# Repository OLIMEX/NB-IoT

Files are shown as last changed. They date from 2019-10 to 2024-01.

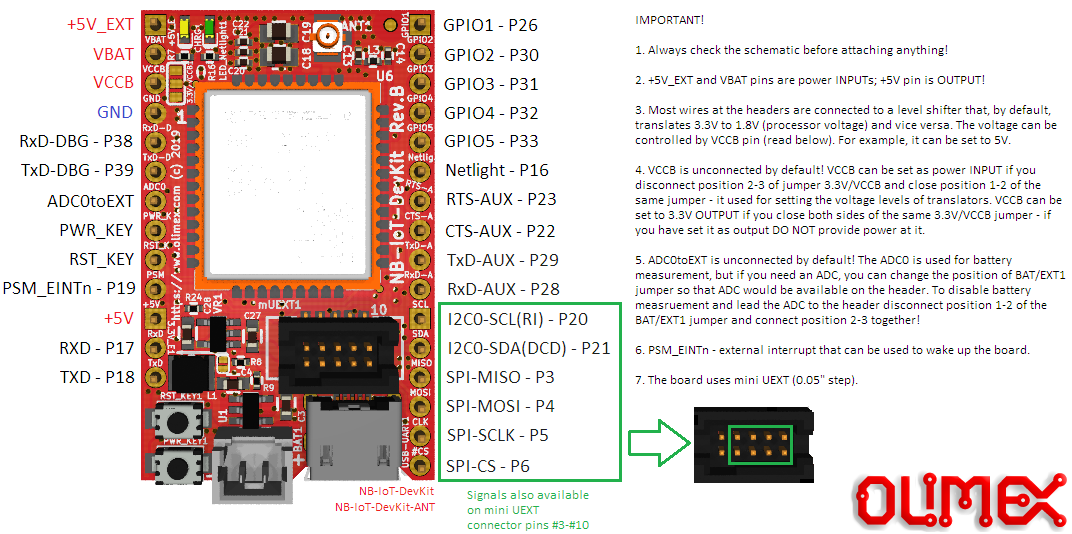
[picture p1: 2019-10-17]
HARDWARE/NB-IoT-DevKit-pinout.png

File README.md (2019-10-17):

# NB-IoT
NB-IoT is LPWAN technology for IoT with many advantages over LoRa and SigFox.

NB-IoT technology works over existing GSM network. This means all existing GSM networks with LTE can support NB-IoT if the protocol is installed by your GSM operator.
One base cell can talk up to 100 000 NB-IoT nodes. One base cell can establish connection in urban area 1-10km and in rural area 10-100km
One NB-IoT node can last on battery up to 10 years if less 200 bytes per day are transmitted

# NB-IoT-DevKit board has these features:
- BC-66 all world wide GSM bands coverage
- NB-IoT 25.5 kbps up and down link
- Ultra low power design
- Build in Li-Po battery charger
- Nano SIM
- Level shifters for 5x GPIOs, I2C, SPI, UART
- Micro UEXT connector
- U.FL antenna connector
- Status LEDs
- Dimensions 40x25 mm

# License
- Hardware is with CERN OHL v1.2 license
- Software is with GPL3 license
- Documentation is with CC BY-SA 4.0 license

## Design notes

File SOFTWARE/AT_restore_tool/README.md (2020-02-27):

This is AT restore firmware procedure for Olimex NB-IoT-Devkit

It should be used if you overwrote the AT command firmware. It is made for Linux.

####################################################

Preparation:

Download all files from the folder where this README is located. 

In order to install a patched CH340 driver, please run "install_ch340.sh" file:

1. Open terminal in the directory containing "install_ch340.sh".
2. Execute the following: ./install_ch340.sh

The reason is that this script allows CH340T to operate at higher baudrate and enables auto-reset 
function, which is not supported with the official ch340 drivers for Linux.

If you have trouble with the shell script, you can also find the driver here:
https://github.com/OLIMEX/ch340-dkms

If you update the kernel of your Linux installation, you might need to run the installation again!

####################################################

Once the driver is successfully installed:

1. Connect Olimex NB-IoT-Devkit board to your PC

2. Open new terminal in the current directory

3. Enter down: ./REPAIR.SH SN IMEI

where SN and IMEI numbers are written on the top of Quectel BC66 chip. 

Notice that the repair script has auto-detect, so make sure you have only one peripheral using
CH340 connected to the computer.

####################################################

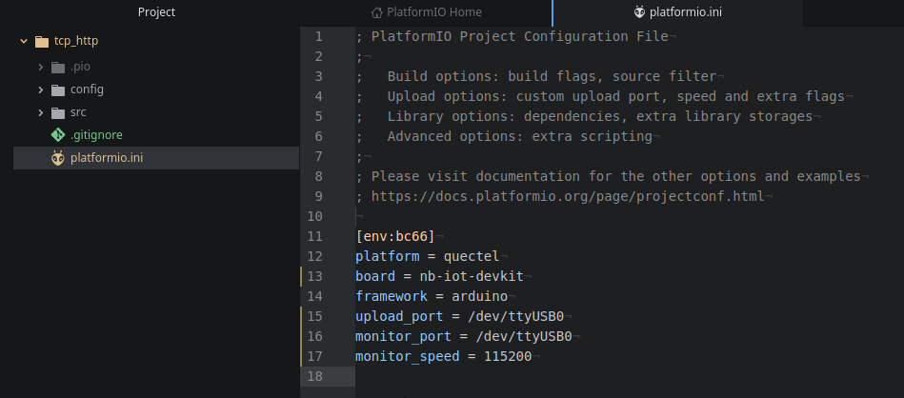
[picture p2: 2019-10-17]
SOFTWARE/images/5_platform_ini.png

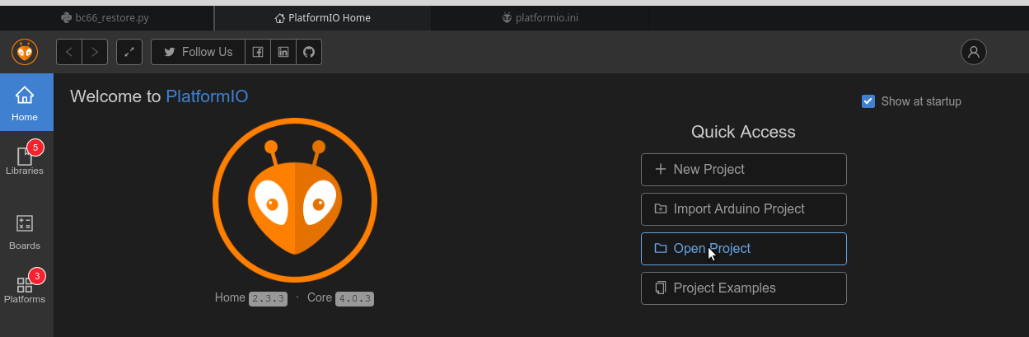
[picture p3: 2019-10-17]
SOFTWARE/images/3_open_project.png

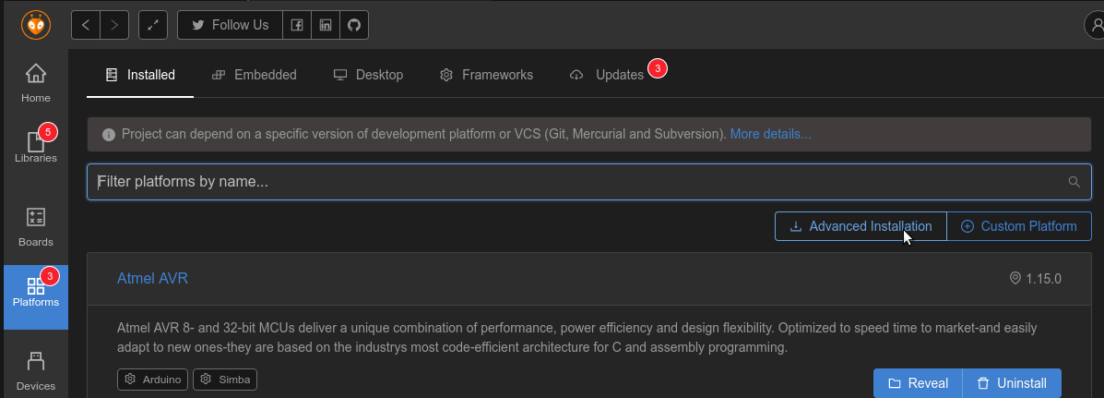
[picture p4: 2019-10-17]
SOFTWARE/images/1_advanced.png

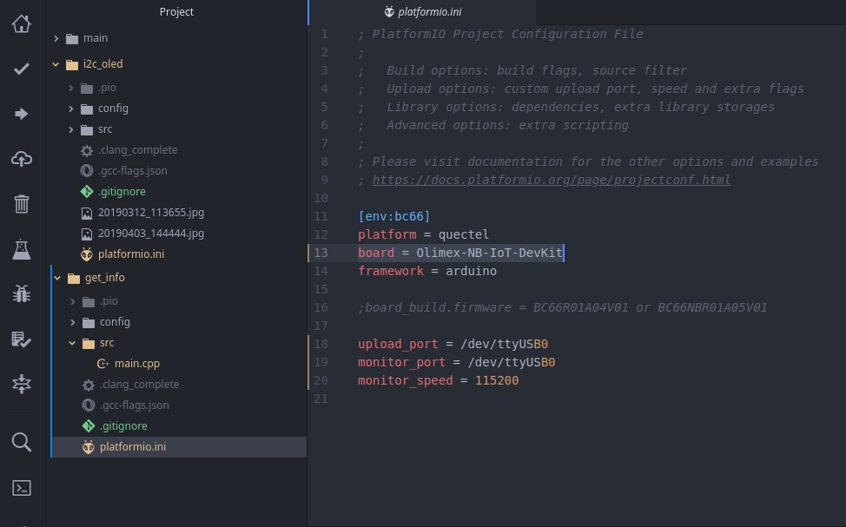
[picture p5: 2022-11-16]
SOFTWARE/images/6_change_settings.png

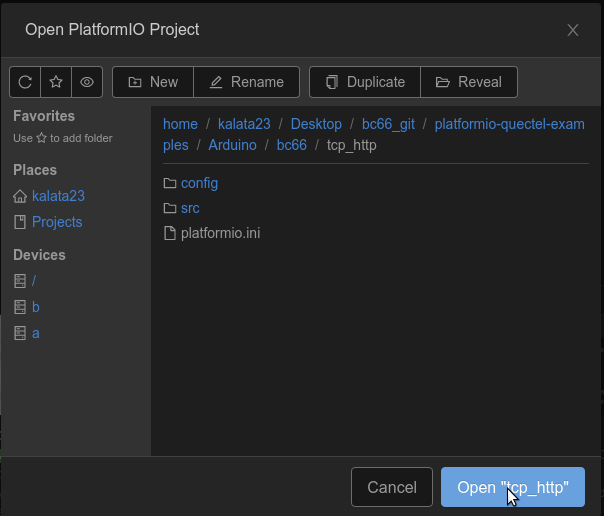
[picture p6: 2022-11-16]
SOFTWARE/images/4_browse.png

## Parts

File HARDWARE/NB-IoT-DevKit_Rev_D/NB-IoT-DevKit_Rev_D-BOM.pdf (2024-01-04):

16:55:51 | NB-IoT-DevKit_Rev_D-BOM | 11/02/2021
Qty | Designation | Package | Designator
1 | 0R/R0402 | L_0402_5MIL_DWS | L3
3 | 22R/R0402 | R_0402_5MIL_DWS | R27,R28,R29
2 | 100R/R0402 | R_0402_5MIL_DWS | R11,R12
5 | 1.5k/R0402 | R_0402_5MIL_DWS | R14,R17,R19,R20,R30
2 | 2.2k/R0402 | R_0402_5MIL_DWS | R7,R10
4 | 4.7k/R0402 | R_0402_5MIL_DWS | R15,R18,R21,R22
3 | 10k/R0402 | R_0402_5MIL_DWS | R6,R16,R26
1 | 49.9k/1%/R0402 | R_0402_5MIL_DWS | R9
2 | 100k/R0402 | R_0402_5MIL_DWS | R1,R31
2 | 220k/R0402 | R_0402_5MIL_DWS | R8,R23
2 | 470k/R0402 | R_0402_5MIL_DWS | R4,R5
6 | 1M/R0402 | R_0402_5MIL_DWS | R2,R3,R13,R25,R33,R32
2 | 27pF/50V/5%/C0G/C0402 | C_0402_5MIL_DWS | C8,C11
4 | 33pF/50V/5%/COG/C0402 | C_0402_5MIL_DWS | C21,C26,C29,C30
1 | 1nF/50V/10%/X7R/C0402 | C_0402_5MIL_DWS | C1
8 | 100nF/10V/10%/X5R/C0402 | C_0402_5MIL_DWS | C6,C12,C15,C16,C20,C23,C24,C25
1 | 4.7uF/6.3V/20%/X5R/C0603 | C_0603_5MIL_DWS | C17
7 | 22uF/6.3V/20%/X5R/C0603 | C_0603_5MIL_DWS | C2,C3,C4,C5,C9,C27,C28
2 | 47uF/6.3V/20%/X5R/C0805 | C_0805_5MIL_DWS | C18,C19
1 | 2.2uH/1.5A/DCR=72mR/20%/ 3.00x3.00x1.50mm/CD32(NR3015T2R2M) | CD32 | L1
1 | FB0603/600R/200mA(160808-601) | L_0603_5MIL_DWS | L2
4 | 1N5819S4/SOD123 | SOD-123_1C-2A_KA | D1,D2,D3,D5
1 | BAT54A(SOT23-3) | SOT23-3 | D4
1 | LED/YELLOW/0603 | LED_0603_KA | CHRG1
1 | LED/Green/0603 | LED_0603_KA | LED_Netlight1
5 | BSS138(SOT23-3) | SOT23 | FET4,FET5,T1,T4,T5
3 | WPM2015-3/TR | SOT23 | FET1,FET2,FET3
2 | BC817(SOT23-3) | SOT23 | T2,T3
1 | Q12MHz/20pF/10ppm/4P/3.2x2.5mm | TSX-3.2x2.5mm_GND(3) | Q1
1 | SY8089AAAC(SOT23-5) | SOT-23-5 | U1
1 | BL4054B-42TPRN(SOT23-5) | SOT-23-5 | U2
1 | AP1231-1.8V(SOT23-5) | SOT-23-5 | VR1
1 | CH340T(SSOP20W) | SSOP-20W | U3
2 | TXB0108PWR(TSSOP-20) | TSSOP20 | U5,U7
1 | PCA9306DCUR(VSSOP-8) | VSSOP-8 | U4
1 | Quectel_NB-IoT_BC66_Module (Pinout-OpenCPU) | Quectel_NB-IoT_BC66_Module-17.7mmx15.8mmx2.0mm | U6
1 | HAB-VCR-010-LF | HAB-VCR-010-LF | mUEXT1
2 | HN1x10 | HN1x10 | EXT1,EXT2
1 | HN1x6 | HN1x6 | EXT3
1 | HN1x3 | HN1x3 | EXT4
1 | DW02S | DW02S | BAT1
1 | U.FL-R-SMT-1 | U.FL-R-SMT-1 | ANT1
1 | SIMNANO-6P-1.3H | SIMNANO-6P-1.3H | SIM1
1 | MISB-SWMM-5B-LF(USB_MICRO) | MISB-SWMM-5B_LF | USB-UART1
2 | IT1185AU2 | IT1185AU2_V2 | RST_KEY1,PWR_KEY1
1 | Soldered/Opened | SJ_2_SMALL | 3.3V/VCCB1
2 | Soldered | SJ_1_SMALLER | 3.3V_E1,Start_E1
1 | BAT:Soldered/EXT:Opened | SJ_2_SMALL | BAT/EXT1
3 | NA/C0402 | C_0402_5MIL_DWS | C13,C14,C22
1 | NA/R0402 | R_0402_5MIL_DWS | R24

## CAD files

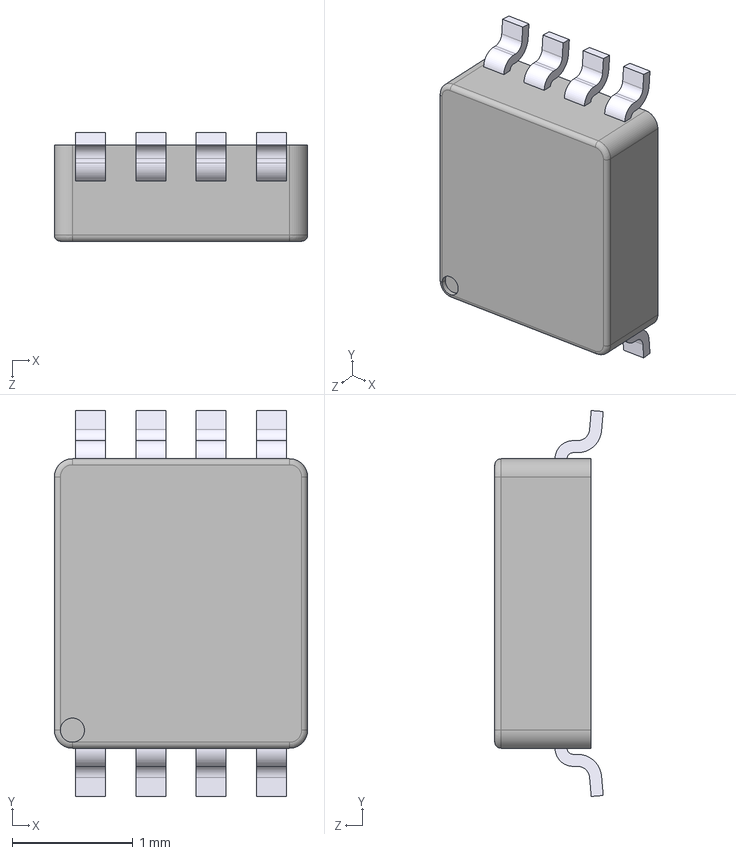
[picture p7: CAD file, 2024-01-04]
HARDWARE/NB-IoT-DevKit_Rev_D/3d/VSSOP8-0.5.STEP
2.10 x 3.20 x 0.9 mm
User Library-VSSOP8-1_Imported
User Library-VSSOP8-1_Imported_2
User Library-VSSOP8-1_Imported_3
User Library-VSSOP8-1_Imported_4
User Library-VSSOP8-1_Imported_5

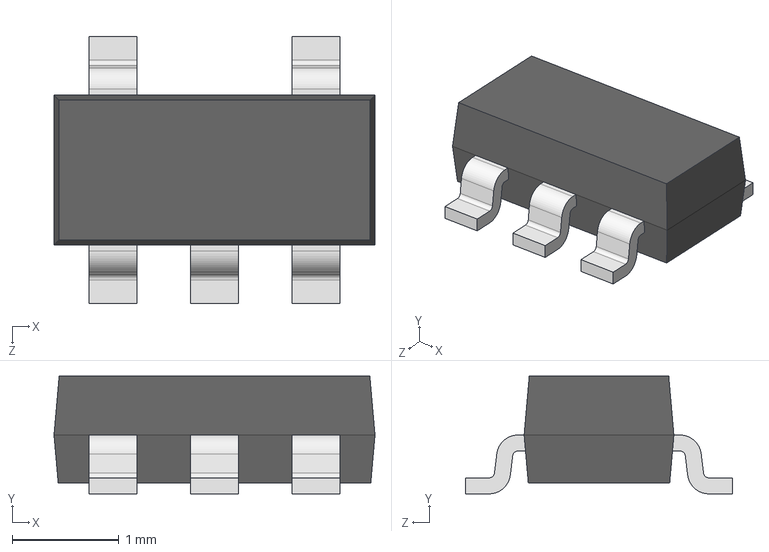
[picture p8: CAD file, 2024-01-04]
HARDWARE/NB-IoT-DevKit_Rev_D/3d/SOT-23-5.step
3.00 x 1.10 x 2.50 mm

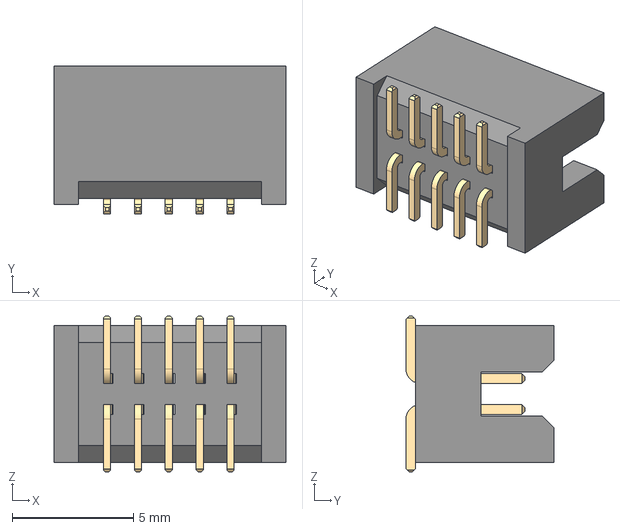
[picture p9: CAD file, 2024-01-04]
HARDWARE/NB-IoT-DevKit_Rev_D/3d/GBH2x5.stp
9.55 x 6.10 x 6.40 mm

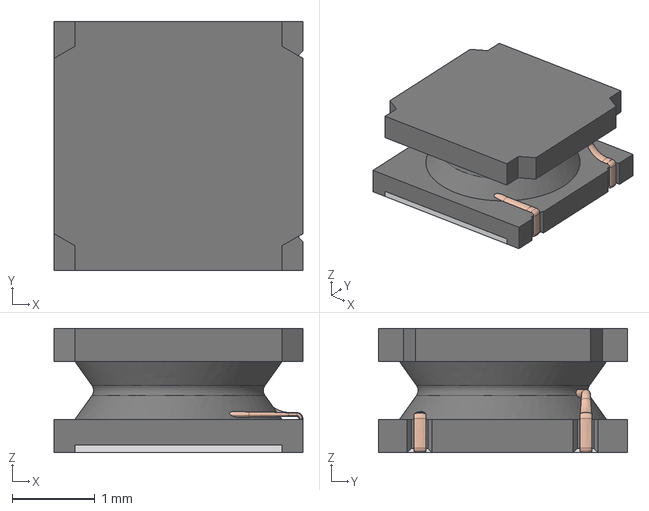
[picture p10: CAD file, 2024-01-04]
HARDWARE/NB-IoT-DevKit_Rev_D/3d/L-CD32_shielded.step
3.00 x 3.00 x 1.50 mm

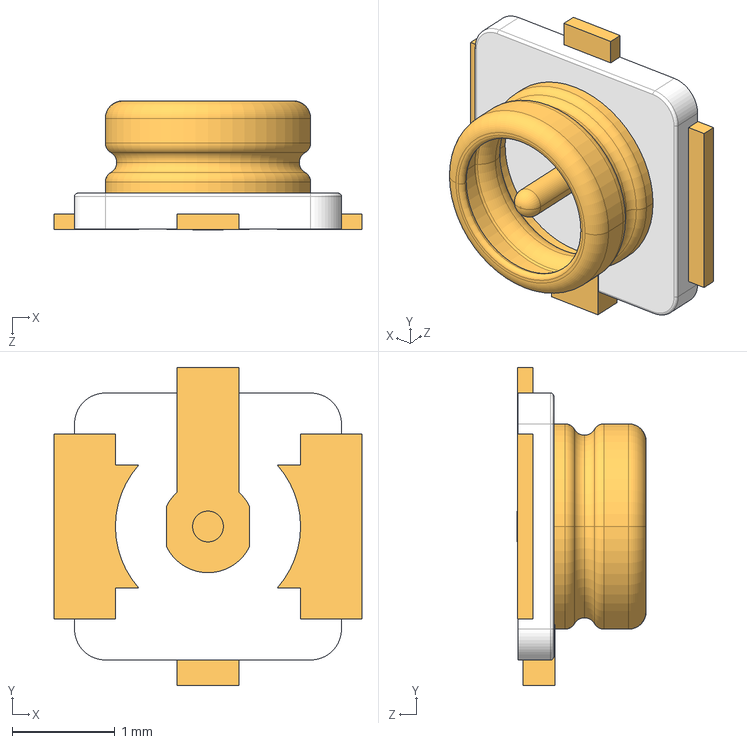
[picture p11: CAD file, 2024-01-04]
HARDWARE/NB-IoT-DevKit_Rev_D/3d/U_FL-R-SMT-1.step
3.00 x 3.10 x 1.26 mm

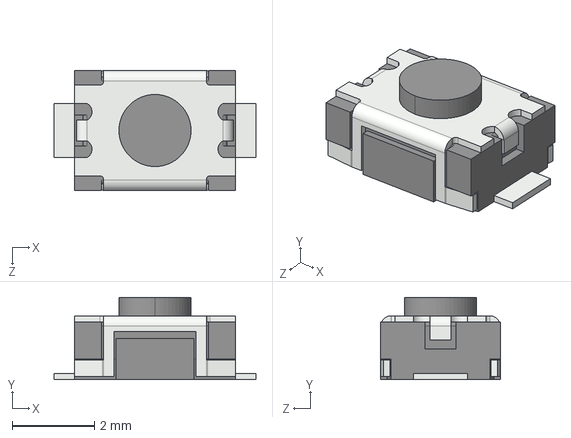
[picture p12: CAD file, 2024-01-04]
HARDWARE/NB-IoT-DevKit_Rev_D/3d/it1185.step
4.90 x 2.00 x 2.90 mm

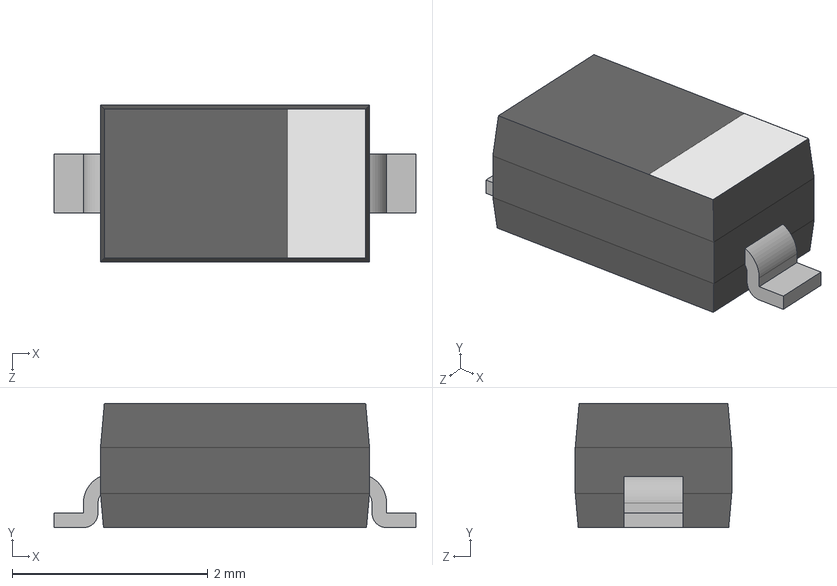
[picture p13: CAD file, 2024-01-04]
HARDWARE/NB-IoT-DevKit_Rev_D/3d/SOD123.step
3.70 x 1.27 x 1.60 mm

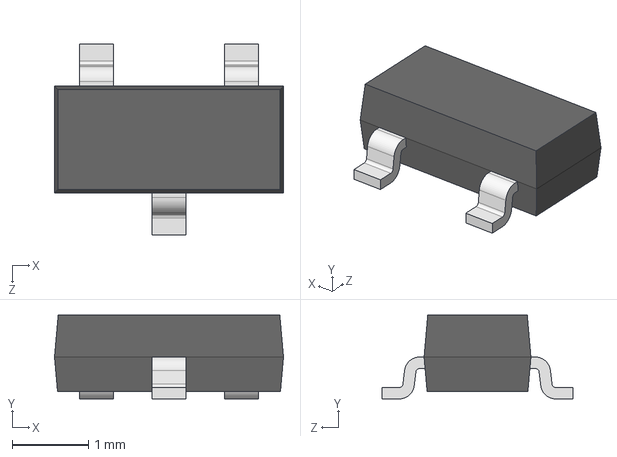
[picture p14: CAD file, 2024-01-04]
HARDWARE/NB-IoT-DevKit_Rev_D/3d/SOT-23.step
3.00 x 1.10 x 2.50 mm

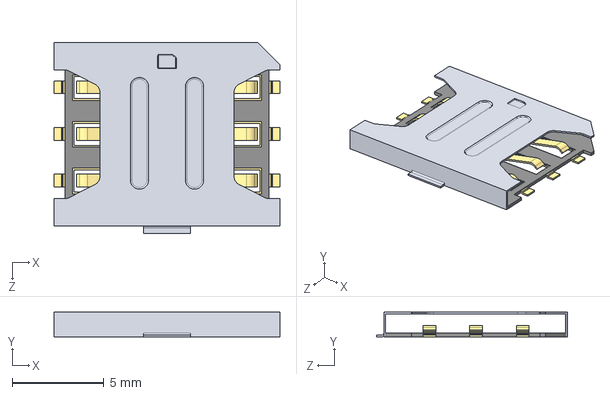
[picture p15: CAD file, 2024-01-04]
HARDWARE/NB-IoT-DevKit_Rev_D/3d/User Library-nano sim.STEP
12.3 x 1.35 x 10.4 mm

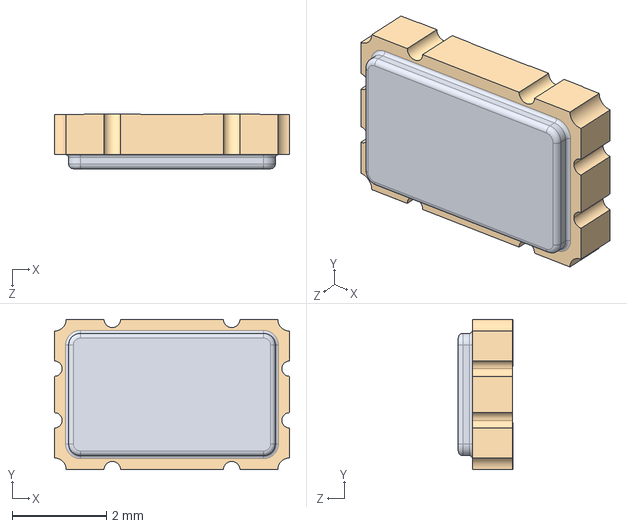
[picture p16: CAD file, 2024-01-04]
HARDWARE/NB-IoT-DevKit_Rev_D/3d/QSG5032.step
5.00 x 3.20 x 1.16 mm

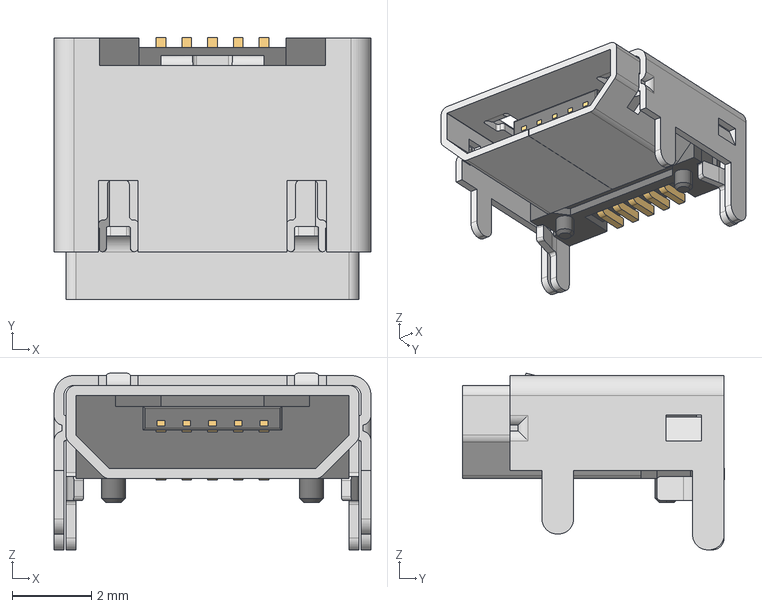
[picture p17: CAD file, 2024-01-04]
HARDWARE/NB-IoT-DevKit_Rev_D/3d/usb_micro_4p.stp
8.00 x 6.60 x 4.46 mm

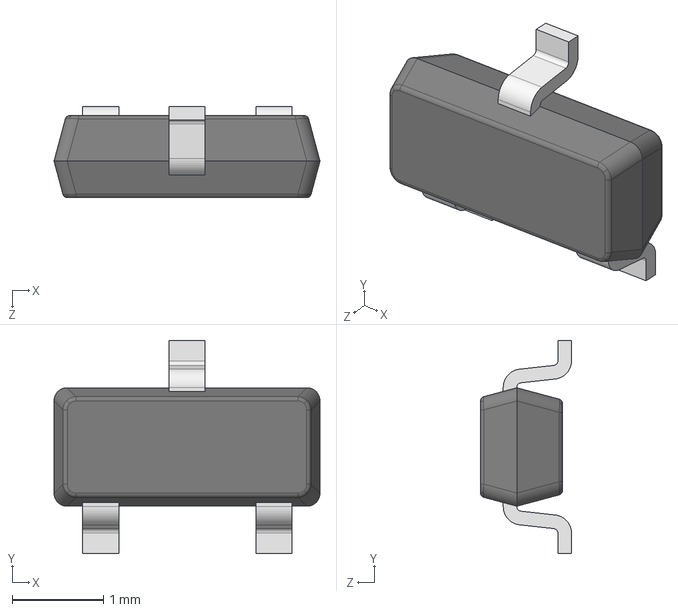
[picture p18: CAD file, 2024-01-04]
HARDWARE/NB-IoT-DevKit_Rev_D/3d/BAT54.step
2.92 x 2.34 x 1.00 mm

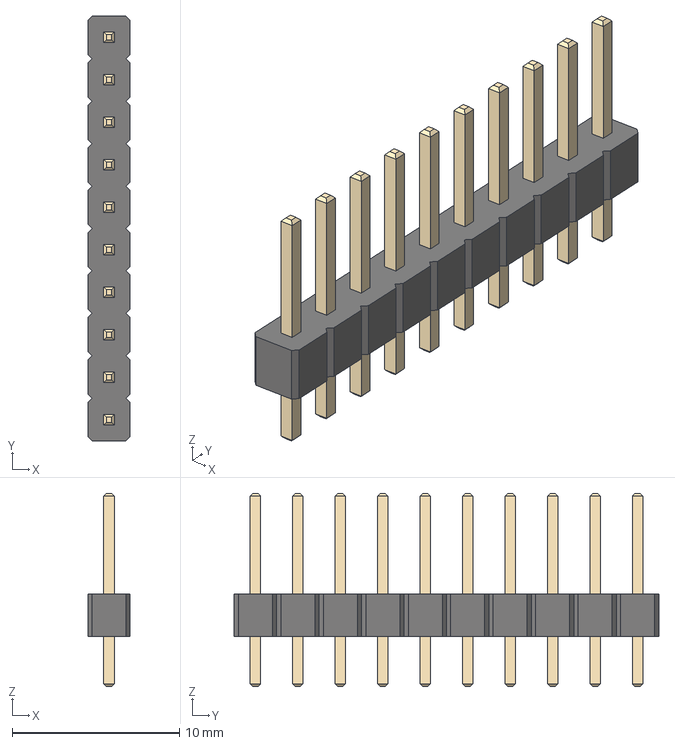
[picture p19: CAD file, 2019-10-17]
HARDWARE/NB-IoT-DevKit_Rev_D/3d/HN1x10-PinHeader_1x10_P2.54mm_Vertical.step
2.54 x 25.4 x 11.5 mm

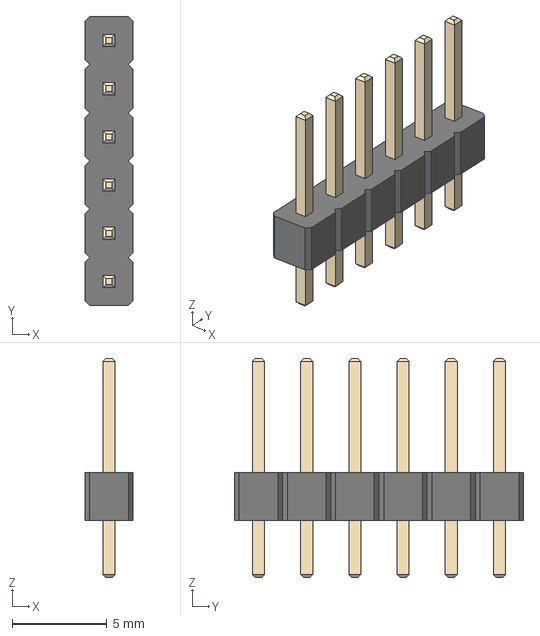
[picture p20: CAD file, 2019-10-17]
HARDWARE/NB-IoT-DevKit_Rev_D/3d/HN1x6-PinHeader_1x06_P2.54mm_Vertical.step
2.54 x 15.2 x 11.5 mm

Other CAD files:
HARDWARE/NB-IoT-DevKit_Rev_D/3d/HN1x3-PinHeader_1x03_P2.54mm_Vertical.step
HARDWARE/NB-IoT-DevKit_Rev_D/3d/Molex_PicoBlade_530470210.step
HARDWARE/NB-IoT-DevKit_Rev_B/3d/NANO-SIM_Wurth_Electronics_693043020611.step

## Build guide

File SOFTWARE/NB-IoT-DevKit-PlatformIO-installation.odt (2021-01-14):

# NB-IoT-DevKit

1. How to install Platformio platform:

1.1 Go to Platforms. Then click on "Advanced Installation" button


1.2 Copy and paste the following link in the text box:
https://github.com/Wiz-IO/platform-quectel

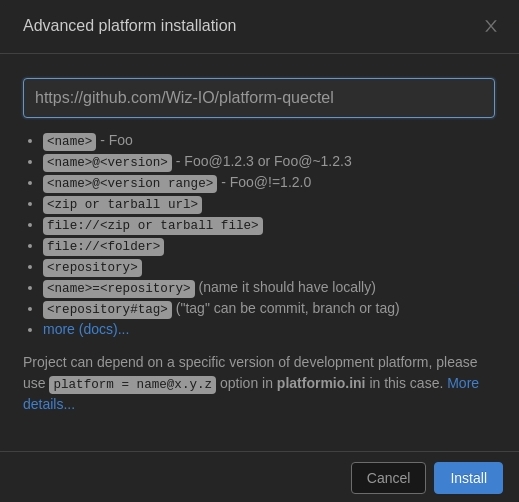
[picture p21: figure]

2. How to import project.

2.1 Click "Open Project" button


2.2 Browse the path to the example project you want to try:


2.3 Click Open

2.4 Open platformio.ini from the left pane


2.5 Change monitor_port and upload_port values with the Serial port of your

device. Change board value to Olimex-NB-IoT-DevKit


2.6 Build the project and upload

NOTE: Before uploading any application, back-up your NVDM.

Firmware, schemes, IoT Flashtool (https://github.com/OLIMEX/NB-IoT)

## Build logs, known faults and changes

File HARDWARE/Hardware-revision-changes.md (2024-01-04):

List of changes between hardware revisions for Olimex NB-IoT-DevKit

NB-IoT-DevKit hardware revision D
---

Overvew: Production optimizations and minor quality improvements, revision not affecting behavior.

1. The SIM1 package changed from SIM-SMT-6P(NASCT-W0012X-06-LF) to SIMNANO-6P-1.3H.
2. mUEXT1's package updated and the silk was enlarged to the real connector's dimensions. Several components were moved.
3. Teardrops set.
4. CE sign added.
5. On several SMD components, the fabrication attributes were changed to surface mount.

NB-IoT-DevKit hardware revision C
---

Overvew: Production optimization, revision not affecting board behavior.

1. The USB-UART1's package corrected - the paste was enlarged with 1.4mil around the small pads so that the distance between to be equal to 10mils.

NB-IoT-DevKit hardware revision B
---

Overview: Initial release.

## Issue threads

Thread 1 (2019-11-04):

How to send AT command to BC66?

shmrymbd, 2019-11-04:
Hi,
Could you share documentation how to send AT command directly to nbiot module?

DanKoloff, 2019-11-06:
You can do that via the USB. You need just USB micro cable, PC and serial terminal.

Connect USB cable between your computer and board's micro USB connector. Check how the NB-IoT-DevKit listed in your computer (for example, if using Windows, open "Windows Device Manager" and find device "USB-SERIAL CH340"). If it is not properly listed or if it is unrecognized make sure to install the CH340T drivers, but this is usually not required.

If everything is alright, remember the name and number of port it got associated with. Install free serial terminal software, I use puTTy and start serial connection on the port that the board is located at. This is how it looks here:

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

Start sending AT commands. Search online for the document that contains the list of AT command for BC66.

shmrymbd, 2019-11-06:
Hi,
1. Thank you for your answer. i have done that and can upload skecth. my issue is to talk direct using AT command right via serial terminal? Currently the code is empty and no serial output. do i need to load some sketch via platform.io to the device?

2. I connect 3.7 rechargable battery after doing programming using usb and the code work but
standalone battery the device not bootup and connect to nbiot network. no led on even i write void setup to turn on led. pls advice because manual is not complete.

3. I have demo tommorow to show running on battery alone. potential 2500u bought from you.

Thank you.

BR
Shamry
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

cskocsis, 2019-11-06:
Netlight only works with + 5V_EXT or USB power.
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

shmrymbd, 2019-11-07:
Hi
I used battery only. yes i agree there will be no net light.

I have the problem the code not running when using battery
 i set void setup… led pin high..

should i remove serial print so code not running if no usb serial? this is my code

#include <Arduino.h>
#include <nbClient.h>
#include <ArduinoJson.h>
#include "RTClib.h"
#include <PubSubClient.h> //

nbClient tcp;
//157.230.38.63  cloud.loranet.my
//219.93.105.37  iot.pernec.com.my
IPAddress server(157, 230, 38, 63); // 157.230.38.63  cloud.loranet.my

int sensor = 9;              // the pin that the sensor is atteched to
int state = LOW;             // by default, no motion detected
int val = 0;                 // variable to store the sensor status (value)

int COUNT = 0;
#define deviceID 001010

void callback(char *topic, byte *payload, unsigned int length)
{
  Serial.printf("[RECEIVE] (%s) %.*s\n", topic, length, payload);
}

PubSubClient client(server, 1883, callback, tcp);

void mqtt_setup()
{
  Serial.println("Start Connection MQTT");
  if (client.connect("xxxxxx", "lorafora", "foralora"))
  {
    // client.publish("pernec/celcom/pos/telemetry/POSBOX-004/", "connected");
    client.publish("pernec/celcom/pos/attribute/POSBOX-004/", "online");
    Serial.println("publish...");
    client.subscribe("inTopic");
    Serial.println("subscribe...");
  }
}

void setup()
{
  String imei;
  Dev.noSleep();
  Serial.begin(115200);
  Serial.printf("POSBOX %s\n", Dev.getVersion());
  pinMode(LED, OUTPUT);
  pinMode(12, OUTPUT);    // initialize sensor as an input
  pinMode(sensor,INPUT_PULLDOWN);    // initialize sensor as an input

  Dev.getImei(imei);
  Serial.printf("IMEI %s\n", imei.c_str());
  Dev.waitSimReady();
  Serial.println("Sim Ready");

  Dev.setBand(8);
  Dev.waitCereg();
  delay(200); // must
  Serial.println("Net Ready");
  mqtt_setup();
  digitalWrite(12, HIGH);
}

int check()
{
  int t = millis();
  int getReceiveLevel = Dev.getReceiveLevel();
  Serial.printf("Rx level     %d dbm\n", getReceiveLevel);
  Serial.printf("Rx quality   %d\n", Dev.getQuality());
  Serial.printf("Rx access    %d\n", Dev.getAccess());
  Serial.printf("Cell cid     %d\n", Dev.getCid());
  Serial.printf("Cell tac     %d\n", Dev.getTac());
  char mlts[322];
  Dev.getMlts(mlts, 322);
  Serial.printf("Cell mlts    %s\n", mlts);
  return(getReceiveLevel);
  Serial.printf("Elapsed: %d mili seconds\n", millis() - t);
}

void execute()
{
  int temp = check();
  COUNT = COUNT + 1;
  // String mystring = "{\"count\":\""+ String(COUNT) + "\",\"rssi\":\"" + String(temp) + "\",\"ts\":\"" + String(1573023292)+"\"}";
  String mystring = "{\"count\":\""+ String(COUNT) + "\",\"rssi\":\"" + String(temp) + "\"}";
  Serial.println(mystring);

  char buf[200]; // Put whatever length you need here
  String(mystring).toCharArray(buf,200);
  client.publish("pernec/celcom/pos/telemetry/POSBOX-004/",buf);
}

void detect()
{
val = digitalRead(sensor);   // read sensor value
  if (val == HIGH) {           // check if the sensor is HIGH
    digitalWrite(LED, HIGH);   // turn LED ON
    delay(100);                // delay 100 milliseconds

    if (state == LOW) {
      Serial.println("Motion detected!");
      Serial.println("==================================");
      execute();
      state = HIGH;       // update variable state to HIGH
    }
  }
  else {
      digitalWrite(LED, LOW); // turn LED OFF
      delay(200);             // delay 200 milliseconds

      if (state == HIGH){
        Serial.println("==================================");
        Serial.println("Motion stopped!");
        state = LOW;       // update variable state to LOW
    }
  }
}

void loop()
{
  detect();
  client.loop();
}

BR
Shamry
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

Closed 2019-11-06.

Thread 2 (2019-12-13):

BC66 Unable to communicate with Linux over USB

spit4520, 2019-12-13:
Hello,

I am unable to connect with the device over usb and perform backup's or flash. I just bought the device and I got it today.

Please see the related ticket: https://github.com/Wiz-IO/Arduino-Quectel-BC66/issues/16

Thanks

DanKoloff, 2019-12-13:
Did you try holding PWR_KEY1 and/or RST_KEY to turn it on?

Also check here: https://github.com/OLIMEX/NB-IoT/blob/master/SOFTWARE/AT_example

spit4520, 2019-12-16:
Yes I have successfully flashed the board. I am trying to now restore the board to a state where I can write AT commands to it (I flashed the board before setting the APN by mistake) If you have any advice please advise

see related issue: https://github.com/Wiz-IO/Arduino-Quectel-BC66/issues/16

spit4520, 2019-12-16:
Hello!

I have an update to the issue. I have been speaking with Georgi Angelov with his PlatformIO implementation of your board. Apparently on windows there is a second COM created that is for direct AT commands to the modem, but on Unix like devices with the CM34X driver I am only able to see /dev/ttyUSB0 and that is the serial/debugging interface NOT the AT command interface. He suggested I contact you directly for support on the Linux/MacOS implementation of the driver. I will road map the process for the software stack and add it into the Wiki so this issue is hopefully resolved in the future :)

Let me know what the next steps would be!

Scott

DanKoloff, 2019-12-17:
Scott, we are writing a short guide on how to restore AT firmware. Should be done later today.

Yet, about the driver and the second serial interface, I believe it is not possible to get two interfaces via a driver update. CH340T has one serial interface, single-channel. You are probably comparing our design with boards that have dual-channel serial converters, which might have the option for two serial interfaces.

DanKoloff, 2019-12-17:
Try this: https://github.com/OLIMEX/NB-IoT/tree/master/SOFTWARE/AT_restore_tool

Closed 2020-10-13.

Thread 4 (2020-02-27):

Getting error "Wrong SN number"

ASL07, 2020-02-27:
Hi,

I have installed the drivers using the https://github.com/OLIMEX/ch340-dkms repo.
The install_ch340.sh script provided on this repo fails with the error `Expected ( at line 19`

The BC66 devkit is connected to the pc and detected as a serial port (ttyUSB0)
When I run REPAIR.sh I get the following error
`Wrong SN number`

Could you give some clues on why it is failing?
Thanks

kalata23, 2020-02-27:
Hi, ASL07,
Unfortunately there was issue with README not displaying the parrameters of 'REPAIR.sh' which I think is the case of your issue.
Syntax is:

`./REPAIR.sh SN IMEI SerialPort`

Both **SN** and **IMEI** are written on the metal plate of the BC666 module. **Serial port** should be something like **/dev/ttyUSB0**, but the digit in the end can differ.

Command execution example:

`./REPAIR.sh MPA19BS1F020305 86787890123456123  /dev/ttyUSB0`

Please keep a note, that SN and IMEI numbers  you pass to the script file, must match with the ones written on the metal plate.

Kaloyan

ASL07, 2020-02-27:
Hi,
Do I have to press reset key or power key when I run the script?
I am pressing reset key after starting the script, but it fails most of the times.
I was able to get `Removing app.......................[ DONE ]` only once, and I always get ` Restoring nvdm.....................[ FAILED ]
`

ASL07, 2020-02-27:
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

It works now.
We need to press reset AFTER a couple of seconds after the script outputs `Removing app......................` or `Restoring nvdm.....................` . If the reset button is pressed too soon then it fails

kalata23, 2020-02-27:
Can you tell me the revision of the board that u have? You shouldn't be forced to press RST button.

ASL07, 2020-02-28:
Yes, if you tell me where to find it... The only thing I can see is 2019

kalata23, 2020-02-28:
> Yes, if you tell me where to find it... The only thing I can see is 2019

 It should be next to the BC66 module.

ASL07, 2020-02-28:
> > Yes, if you tell me where to find it... The only thing I can see is 2019
>
> It should be next to the BC66 module.

It's Rev B

kalata23, 2020-02-28:
No need to manually reset the board with Rev B. The flash tool resets the board. Maybe you have bad USB connection (bad usb cable or not properly plugged).  Also to avoid reset issue, you can try to disconnect the board and connect it seconds before executing the REPAIR.sh script. Keep in mind that all Serial connections with the board should be closed before executing REPAIR.sh.

Kaloyan

ASL07, 2020-02-28:
> No need to manually reset the board with Rev B. The flash tool resets the board. Maybe you have bad USB connection (bad usb cable or not properly plugged). Also to avoid reset issue, you can try to disconnect the board and connect it seconds before executing the REPAIR.sh script. Keep in mind that all Serial connections with the board should be closed before executing REPAIR.sh.
>
> Kaloyan

I have tested this again
Disconnecting the board and reconnecting it just before the script is run helps, but it fails sometimes.
If the board is already connected, then I have to press the reset button for it to work

ASL07, 2020-08-24:
#3
Hi,
Now the restore.sh script does not work at all
Previously, connecting the USB would make it work intermittently, but right now, it does not work at all.

Is there a way to restore AT functionality using IoT flash tool on Windows, or even Qflash?

I have a device backup but whenever I try to flash it with Qflash or flashtool I get "Format error"

kalata23, 2020-08-24:
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

What version of the firmware did you use before uploading your own application?
Does restore.sh give you any error messages?

Closed 2020-10-13.

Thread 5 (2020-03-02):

USB UART AT command interface becomes unresponsive after some time

ASL07, 2020-03-02:
Hi,

I am testing this board in AT command mode.
I have it connected to my computer through USB and I am sending AT commands to it using the OS X screen tool
After several minutes, the modem becomes unresponsive, it doesn't respond to any characters sent to the USB port

If I reset the board using the reset button, the USB interface works again

DanKoloff, 2020-03-02:
Maybe some sleep mode gets enabled? Not sure what is set by default.

ASL07, 2020-03-02:
That was it, I disabled sleep mode with Ql_SleepDisable() and now it's not happening.
Thanks!

Closed 2020-03-02.

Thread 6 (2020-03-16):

Fatal error: os_wizio.h: No such file or directory

Humancell, 2020-03-16:
Hello,

I'm just getting going, and when I attempted to build I got: .../framework-quectel/arduino/cores/bc66/interface.h:27:10: fatal error: os_wizio.h: No such file or directory

I followed the steps to install: https://github.com/OLIMEX/NB-IoT/blob/master/SOFTWARE/NB-IoT-DevKit-PlatformIO-installation.pdf

Everything went well up to the build.  Are there steps that are missing that would have installed the other files?  I just did a git clone of your repo ...

DanKoloff, 2020-03-17:
Try using the master branch instead:

https://github.com/Wiz-IO/platform-quectel

It has configuration of the Olimex board as far as I can see here:

https://github.com/Wiz-IO/platform-quectel/tree/master/boards

Also make sure to install this driver since it allows higher baud rate:

https://github.com/OLIMEX/ch340-dkms

Closed 2020-10-13.

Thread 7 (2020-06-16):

Cannot use 5V logic. Level shifter not working when jumper closed between 1-2 and open betwee 2-3

ASL07, 2020-06-16:
Hi,
I am using BC66 dev kit.
I need to interface a 5V logic device.
I have soldered the jumper between position 2 and 1 (VCCB), so now VCCB is supposed to be an INPUT, as per your documentation
I have connected both 5V_EXT and VCCB to 5V.

Then, I am using a simple program which simply sets GPIO1 HIGH

Expected:
GPIO1 Voltage is 5V (VCCB)

Actual:
GPIO1 voltage is ~2.4V

If I leave VCCB unconnected (same jumper set-up), then GPIO1 is ~2.9V at high level

DanKoloff, 2020-06-17:
> I have soldered the jumper between position 2 and 1 (VCCB), so now VCCB is supposed to be an INPUT, as per your documentation

Did you cut the original connection between position 3 and 2?

ASL07, 2020-06-17:
Yes,
I have only connected position 1-2, position 2-3 are disconnected

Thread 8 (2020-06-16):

GPIO HIGH level is 1.45V when VCCB is set to output (BC66 devkit)

ASL07, 2020-06-16:
Hello,

I have closed both position 1-2 and 2-3 of the VCCB/3v3 jumper.

Now, I have a simple test program which just sets GPIO1 to HIGH

I would expect GPIO  high level to be 3v3, however it is 1.45V

Could you tell me what the problem is, or help to troubleshooting it?

DanKoloff, 2020-06-17:
It is illegal to have both positions closed...

ASL07, 2020-06-17:
Hello,

Your documentation says otherwise. It clearly says that in order to use the VCCB pin as 3v3 output, both positions of the jumper should be closed. Please see below:

https://github.com/OLIMEX/NB-IoT/blob/master/HARDWARE/NB-IoT-DevKit-pinout.png

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

DanKoloff, 2020-06-17:
Yeah, this is true. I am testing it right now, my initial tests shows ~3.3V at GPIO1 with a board from the shop without any hardware or software changes. I power via the micro USB. After closing both jumpers I also measure 3.3V at VCCB pin. Will test with some toggle code now and will update you.

DanKoloff, 2020-06-17:
OK, so it seems I can replicate the problem for both this issue and https://github.com/OLIMEX/NB-IoT/issues/7

It doesn't occur if I use oscilloscope to measure but it appears if I use multimeter. In fact the issue appears if I use three different multimeter tools and never occurs with the oscilloscopes, it also doesn't happen if I use 10 MOhm resistor. I shot a video with the oscilloscope:

https://www.youtube.com/watch?v=6IA7m9HBqNU

I believe the TXB0108PWR gets somehow disturbed by the multimeter tool, but can't find anything in the datasheet so far.

ASL07, 2020-06-17:
Hello,
Thanks for your testing
Now that you mention this, I was experiencing very weird behaviour when measuring GPIO1 with a portable scope. The Voltage level on GPIO1 would change whenever I disconnected and reconnected the scope...

I thought it could be a bad reading from the scope, but now that you mention the multimeter causes disturbances, it could also be that connecting the scope causes the voltage to change...

Will do more tests later on and update this issue

Please let me know if you make any more progress

DanKoloff, 2020-06-18:
> Btw, have you been able to get the GPIO working at 5V? By using VCCB as input and providing 5V_EXT, as I mentioned in #7 ?

Yes. Same behavior exactly. No multimeter attached = no problem. As soon as I attach the multimeter voltage goes down. It is the same if I kept it during power up.

No issues if I use oscilloscope tho or if I attach 10 mega ohm resistors instead.

ASL07, 2020-06-18:
I have connected a 5V logic sensor (HC-SR04) to the module and I can interface it properly.

It is really weird that it only happens when you connect a multimeter

DanKoloff, 2020-06-18:
I also don't have idea why it happens, but I am glad we discovered it.

DanKoloff, 2020-06-19:
We investigated further. It seems the multimeters have high capacitance and the TXB0108PWR buffer bugs at around 70pF as per datasheet:

"The TXB0108 is designed to drive capacitive loads of up to 70 pF. The output drivers of the TXB0108 have low dc drive strength. If pullup or pulldown resistors are connected externally to the data I/Os, their values must be kept higher than 50 kΩ to ensure that they do not contend with the output drivers of the TXB0108."

You can now find the documents here: https://github.com/OLIMEX/NB-IoT/tree/master/DOCs

There is a workaround if you want to measure with such tool - add a resistor in series between the board and the tool. I used 200 kOhm resistor and this allows the measurement.

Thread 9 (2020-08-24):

Board is not powering up unless USB is connected

ASL07, 2020-08-24:
Hello,

I am having a strange issue with my board.

I followed this and have connected position 1-2 and disconnected position 2-3 of the jumper, in order to set VCCB as power input
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

I expect the board to power on whenever I connect 5V to VCCB, but it doesn't power up unless I connect the USB as well

I tried also connecting a battery but nothing changes either

DanKoloff, 2020-08-24:
Did you provide 5V to pin #1 +5V_EXT too? The jumpers and VCCB power input set the buffers but you still need to provide input +5V_EXT.

Important! When you provide 5V to VCCB and 5V to the input all GPIOs would become 5V. Make sure you don't have 3.3V peripherals connected to GPIOs or they might get damaged.

ASL07, 2020-08-24:
Hi,
I should have mentioned.
Yes am providing 5V to both 5V_EXT and VCCB
And yes, I want all GPIO to have 5V logic

ASL07, 2020-08-24:
Sorry, my fault, it was a power supply issue. I switched to a more reliable one and now it works.

Closed 2020-08-24.

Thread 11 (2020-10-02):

AT Commands from external MCU

Simonefardella, 2020-10-02:
Hi, it's possible to interface this module with external MCU and send AT Commands from (for example) an Arduino or ESP32?

It's possible to have some examples?
Thanks

DanKoloff, 2020-10-13:
Yes, you can control the board from another board via AT commands. For initial evaluation I highly recommend starting with NB-IoT-DevKit or NB-IoT-DevKit-ANT before switching to the designs more suitable for embedding:

https://www.olimex.com/Products/IoT/NB-IoT/NB-IoT-DevKit/open-source-hardware

Simonefardella, 2020-10-27:
Thanks, about the serial AT commands, i have to wire my uart to the PIN 17-18 (TxD-RxD GPIO)?
Thanks

DanKoloff, 2020-10-28:
17 and 18. In NB-IoT-DevKi we have placed the CH340T USB-UART converter to pins 17 and 18.

Simonefardella, 2020-10-28:
Thanks man, i'll close the issue.

artursmet, 2020-11-08:
@DanKoloff Is it possible to use NB-IoT-DevKit (with that USB-UART converter) in the scenario mentioned by @Simonefardella ?
I'd like to do exactly the same thing and I already have the NB-IoT-Devkit. Is there a way to achieve the AT commands control from external MCU using that board?

DanKoloff, 2020-11-09:
Yes, it should be possible but I am not sure of the specifics since I haven't tested it. Few things to consider - USB-UART converter should be at 3.3V DC level; maybe if using the 17/18 pins it would cause problems with the CH340T converter that is placed on the same lines, if that is the case you might want to keep the USB disconnected (or the USB data lines if that is used for powering), if that is not working maybe you would need to isolate CH340T from interfering, but maybe there is a way to set second UART (28/29) for the AT so you don't interfere with the CH340T but not sure how it can be done can't find AT command for it, maybe ask Quectel if there is such firmware (set for pins 28/29).

artursmet, 2020-11-09:
@DanKoloff Thanks for the answer - I'll try contacting Quectel about using the second UART for AT commands.
It looks like the CH340T is interfering still - I'm powering the devkit over `+5V_Ext` pin, the USB is not connected at all.
I've seen the #9 though - should I switch the jumper and provide current also to VCCB, in order to power up the board from external (non USB) power source?

DanKoloff, 2020-11-09:
If you are doing that it should work. Few missteps could have happened: USB-serial RX and TX not being at 3.3V; not have GND of power supply and GND of USB-serial cable connected to board; forgetting to power the board after attaching power supply with the power button; not sending proper string from host board (I always forget about CR LF around AT boards, not sure which or if any of proper ending is required).

artursmet, 2020-11-10:
@DanKoloff Thanks for your help I really appreciate it.
Despite the good wiring, I was unable to use the main ports in my setup. However I had contacted Quectel support and they have shared with me a very helpful hints.

The BC66 supports AT commands only on one UART interface at a time. There is a way (internal AT command) that can be used to switch the AT command interface.
Sharing the syntax:

```
AT+EPORT=1,connl,1
```
first attribute means that we want to switch the interface
`connl` means AT command interface
third attribute is the desired interface which we'd like to use.
```
      0 : UART0 (MAIN)
      1:  UART1 (AUX)
      2:  UART2
      3:  UART3
      4:  USB
      5:  USB
```

Also if you want to switch the hardcoded baud rate, it's possible via

```
AT+EPORT=3,1,9
```
3 - the command will be used in changing baud rate mode
1 - the port from above map (UART AUX in my example)
9 - desired baud rate value (map below)

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

I really recommend contacting Quectel support, they're very responsive.

In my final setup I power up the BC66 devkit on the `+5V_Ext` port, I connect the serial interface on pins 28/29 and I can control the module with AT commands.

DanKoloff, 2020-11-11:
Thank you very much for the update, pretty sure other people would find it helpful in future too! Glad the issue had been solved in such an elegant way!

My experience with Quectel support had always been similarly positive.

Closed 2020-10-28.

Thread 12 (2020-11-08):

Use NB-IoT board as external modem

artursmet, 2020-11-08:
Hi,

Is it possible to use the NB-IoT device with BC66 chip, as external modem connected for example to arduino device over UART?
I have tried to do so, but I can't setup the proper communication.

According to the pinout - https://raw.githubusercontent.com/OLIMEX/NB-IoT/master/HARDWARE/NB-IoT-DevKit-pinout.png there are 3 pairs of RX/TX pins.

- Main pins (P17/P18)
- AUX ports (P28/P29)
- Debug (P38/P39)

Are all those ports usable, while powering the devkit board by the +5V_Ext pin? I'd like to be able to communicate with the devkit board using AT commands, that will be sent from the different module using serial port.
I need to connect them via UART, not over USB.

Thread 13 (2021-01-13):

Unable to compile example projects (missing os_wizio.h)

belveder79, 2021-01-13:
I followed the install instructions for the BC66 module (the one without USB connector) but none of the examples compile as I end up with:

`/Users/arth/.platformio/packages/framework-quectel/arduino/cores/bc66/interface.h:27:10: fatal error: os_wizio.h: No such file or directory`

I'm using latest Atom and PlatformIO on OSX.

DanKoloff, 2021-01-14:
It can be something related to the OSX installation. I think Wiz-IO didn't fully test on a OSX, based on his comment in the description ("test and report "):

https://github.com/Wiz-IO/platform-quectel

belveder79, 2021-01-14:
it is also broken on Windows

DanKoloff, 2021-01-14:
I've update the guide to list proper addresses now. Not sure if the examples re-hosted at our GitHub would work though, maybe use the default ones.

belveder79, 2021-01-14:
Ok, so I got the samples to compile, but I can't get the device to connect at all (just crambled chars - see Olimex Forum post) Anyway, probably there is some issue with the baud rate on the preinstalled image, so I could probably fix it by setting Serial baud rate manually in the upload image. However, it is a bit frustrating as there is essentially no dedicated documentation for the module at all - I have no idea where to start...

Let's say the Arduino examples from Wiz-IO are compiling - how do I get them onto the board? I need to get the board into some bootloader state by pressing buttons, but how to do that here?

DanKoloff, 2021-01-15:
You need DTR and DTS, inspect the schematic of NB-IoT-DevKit:

https://github.com/OLIMEX/NB-IoT/blob/master/HARDWARE/NB-IoT-DevKit_Rev_B/NB-IoT-DevKit_Rev_B.pdf

You can use ESP-PROG for the task:

https://www.olimex.com/Products/IoT/Programmer/ESP-PROG/open-source-hardware

 or use the schematic as basis to understand better:

https://www.olimex.com/Products/IoT/Programmer/ESP-PROG/open-source-hardware

belveder79, 2021-01-15:
ok, the point is I'm not using the DevKit, I'm using the breakout board:

https://www.olimex.com/Products/IoT/NB-IoT/NB-IoT-BC66/resources/NB-IoT-BC66-pinout.pdf
https://www.olimex.com/Products/IoT/NB-IoT/NB-IoT-BC66/resources/NB-IoT-BC66_Rev_B.pdf

So as far as I get the schematics,
- 3.3V is actually fine as power
- level shifters in place should translate 1.8V to 3.3V already but NOT for RxD_main and TXD_main (?)
- I should connect the UART to RxD_main and TxD_main rather than RxD_dbg and TXD_dbg, but need to have my own level shifters in place (?)

DanKoloff, 2021-01-20:
Judging by this forum message the issue is now solved:

https://www.olimex.com/forum/index.php?topic=8037.msg30338#msg30338

However, I am not sure 100% what exactly was the fix - was it solved by using the TXD_MAIN and RXD_MAIN pins (instead of the dbg ones)?

belveder79, 2021-01-24:
yes, actually it was resolved by using the main RX/TX pins. I did not really test flashing the module yes, but merely playing with AT commands...

DanKoloff, 2021-01-27:
Alright thank you for the feedback, I am sure your feedback would help other people in future. Closing the issue now as resolved.

Closed 2021-01-27.

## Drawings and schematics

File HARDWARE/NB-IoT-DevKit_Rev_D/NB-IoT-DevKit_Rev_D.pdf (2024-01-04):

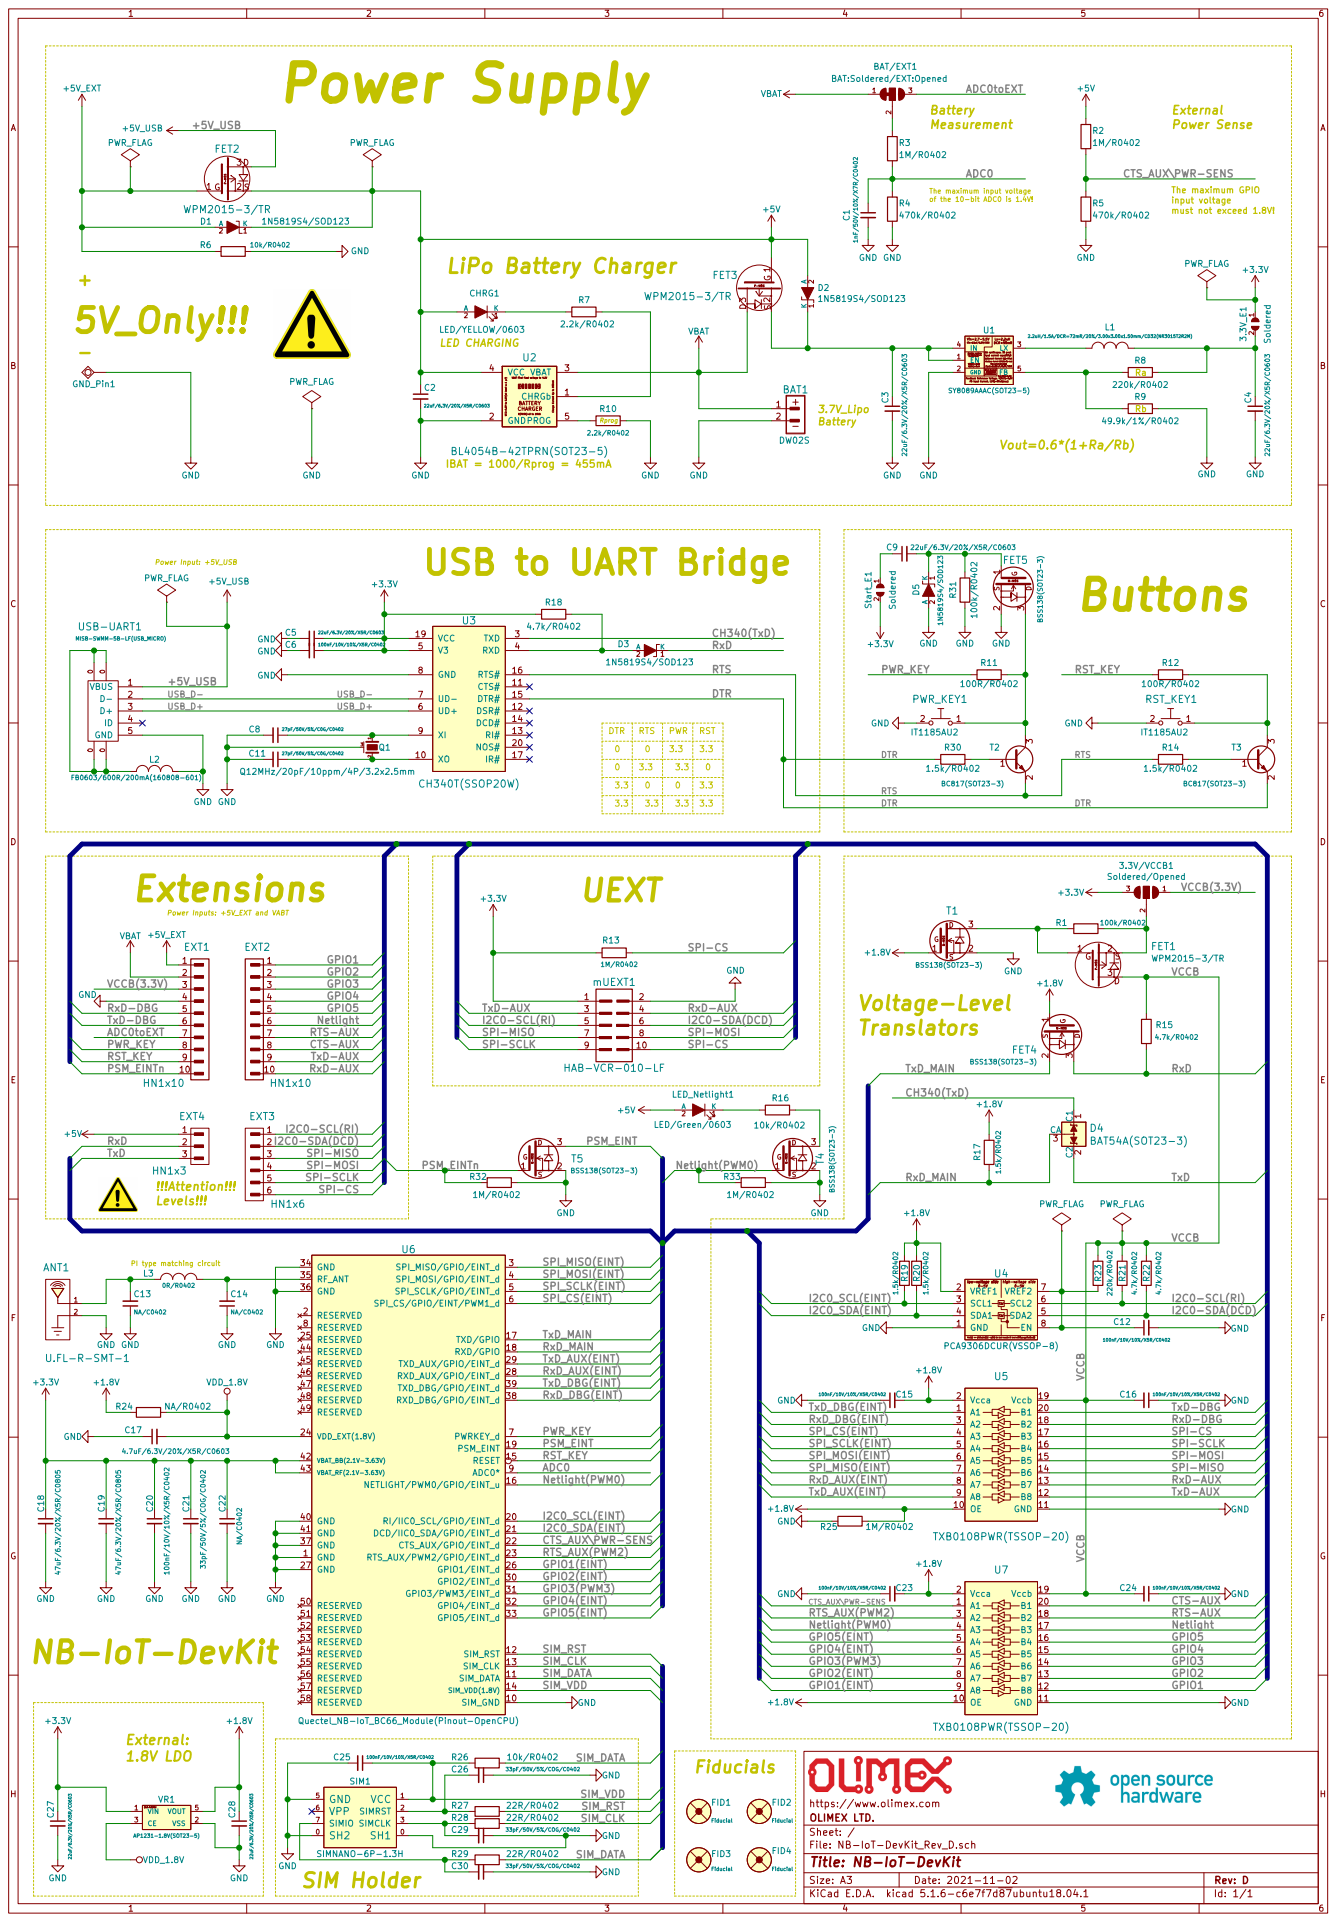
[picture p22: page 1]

Power Inputs: +5V_EXT and VABTPower Supply

3 BAT/EXT1 BAT:Soldered/EXT:Opened

The maximum input voltage of the 10-bit ADC0 is 1.4V! DTR

The maximum GPIO
input voltage must not exceed 1.8V!

2 CHRG1
Ra LED CHARGING USB to UART Bridge

load current capability! Lx=2.2uH

Do not float. Enable control. FB Input Current, I(FB)=50nA(max) Feedback Reference Voltage, V(REF)=0.6V

TxD-DBG
!!!Attention!!! Levels!!! NB-IoT-DevKit

SPI-MISO
SPI-MOSI SPI-SCLK

PWR_FLAG
I2C0-SCL(RI) RxD-AUX
I2C0-SDA(DCD)

PI type matching circuit
+1.8V GND GND

SPI_MOSI(EINT) SPI_MISO(EINT) SPI_SCLK(EINT) SPI_CS(EINT)

TxD_AUX(EINT) RxD_AUX(EINT) CTS_AUX\PWR-SENS

Id: 1/1 Title: NB-IoT-DevKit File: NB-IoT-DevKit_Rev_D.sch Sheet: / OLIMEX LTD. https://www.olimex.com

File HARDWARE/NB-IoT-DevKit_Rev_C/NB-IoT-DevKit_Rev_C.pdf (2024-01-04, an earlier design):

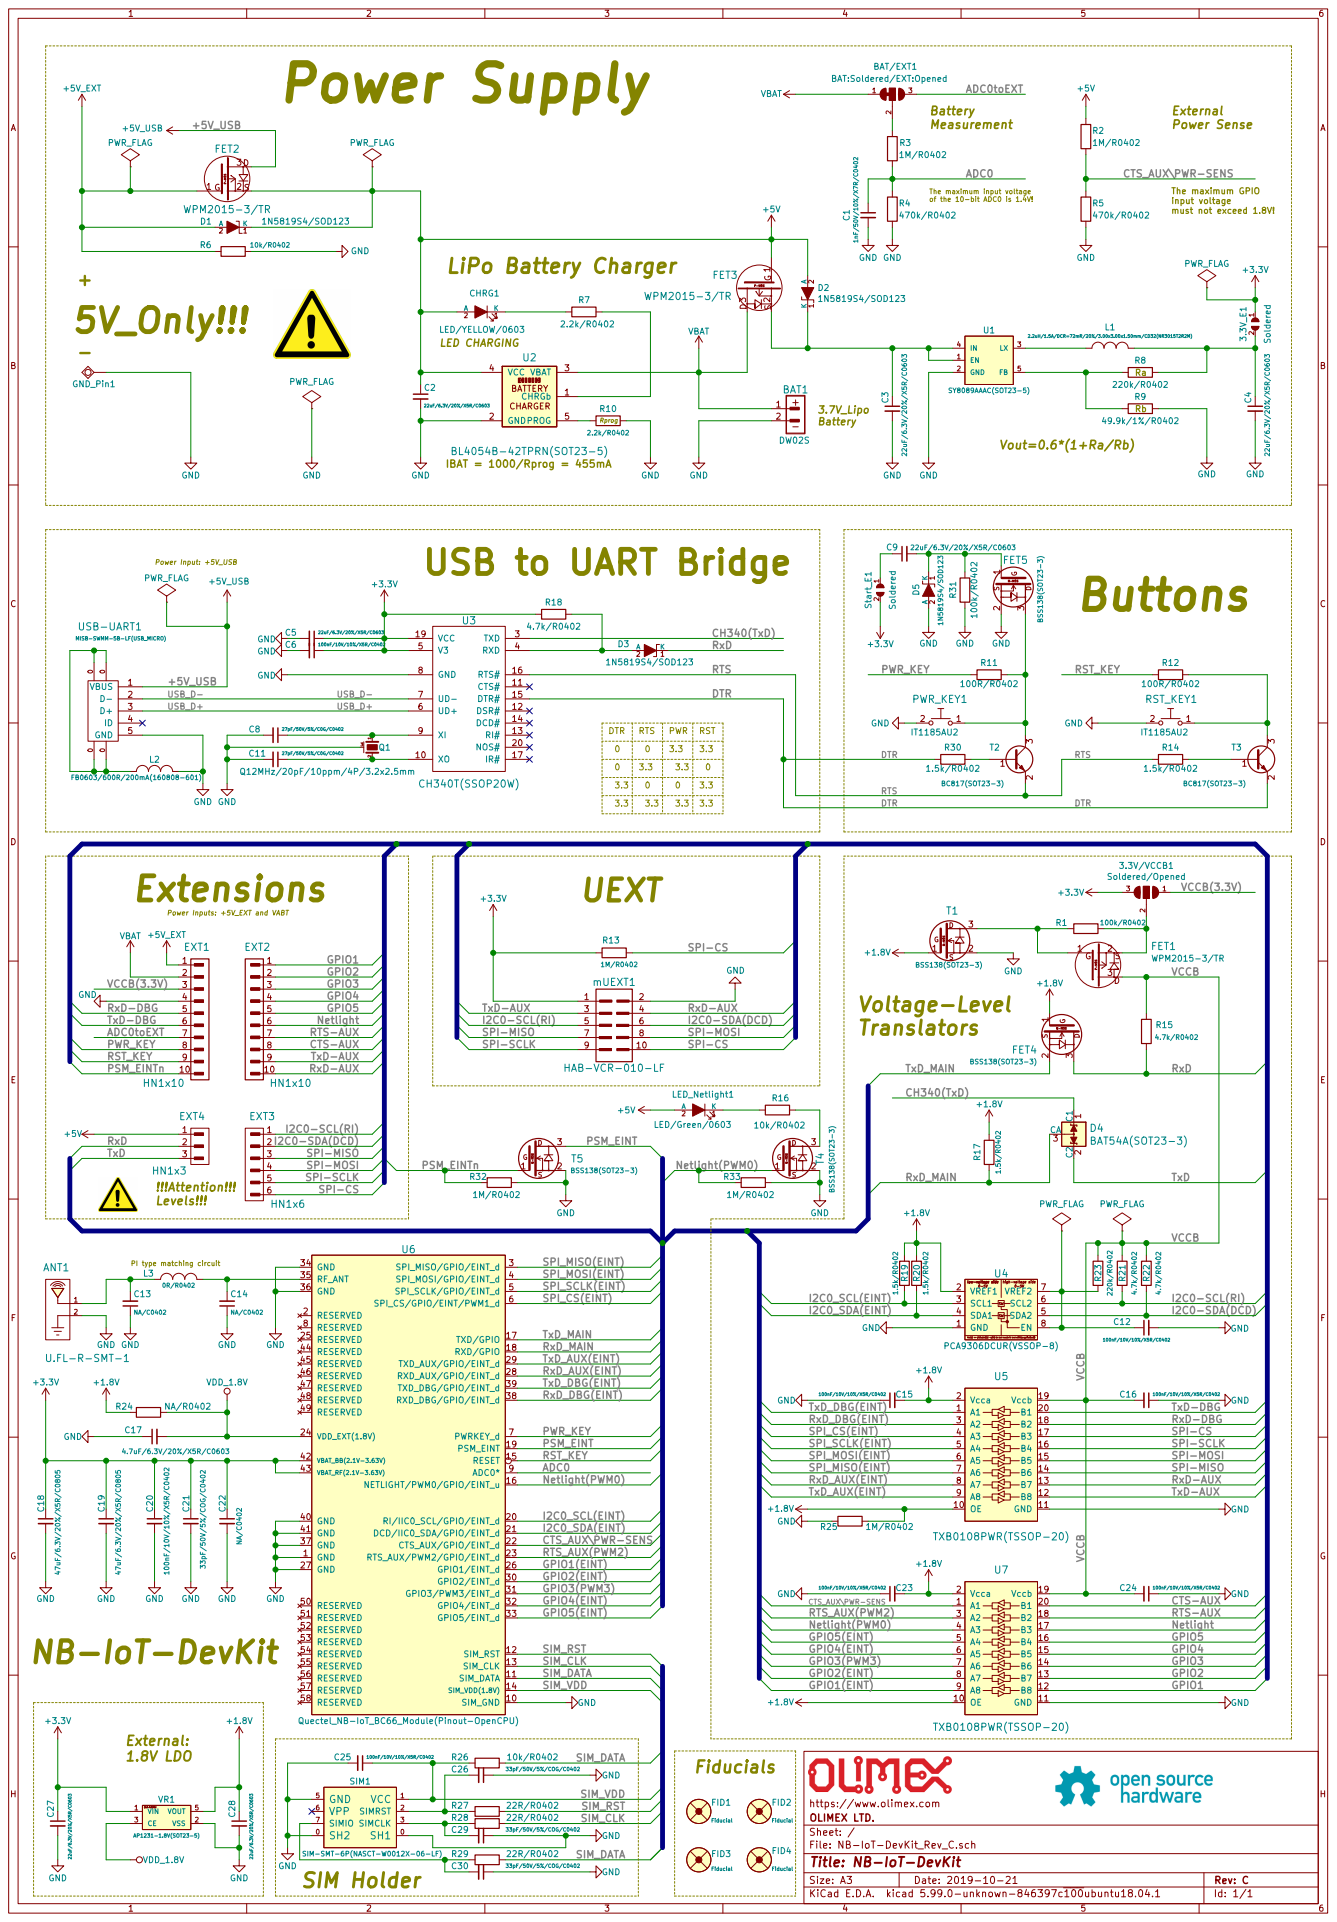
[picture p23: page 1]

1M/R0402 Battery Measurement ADC0 C1 1nF/50V/10%/X7R/C0402 GND GND

input voltage must not exceed 1.8V!

!!!Attention!!! Levels!!! Power Inputs: +5V_EXT and VABT

Netlight RTS-AUX CTS-AUX GPIO4 GPIO3 GPIO2 GPIO1 ADC0toEXT PSM_EINTn RST_KEY

RxD-DBG
I2C0-SCL(RI) TxD-DBG

SPI-MISO
SPI-MOSI SPI-SCLK

TxD
I2C0-SDA(DCD) SPI-MISO

Id: 1/1 Title: NB-IoT-DevKit File: NB-IoT-DevKit_Rev_C.sch Sheet: / OLIMEX LTD. https://www.olimex.com

SIM-SMT-6P(NASCT-W0012X-06-LF)

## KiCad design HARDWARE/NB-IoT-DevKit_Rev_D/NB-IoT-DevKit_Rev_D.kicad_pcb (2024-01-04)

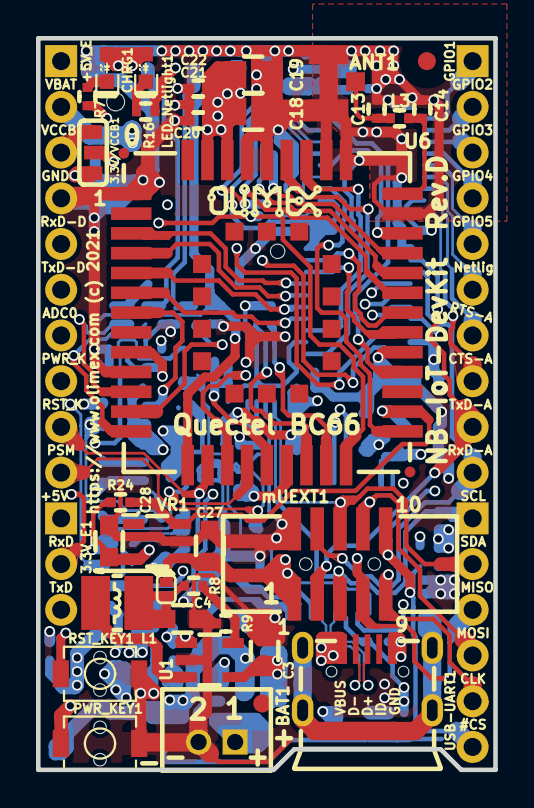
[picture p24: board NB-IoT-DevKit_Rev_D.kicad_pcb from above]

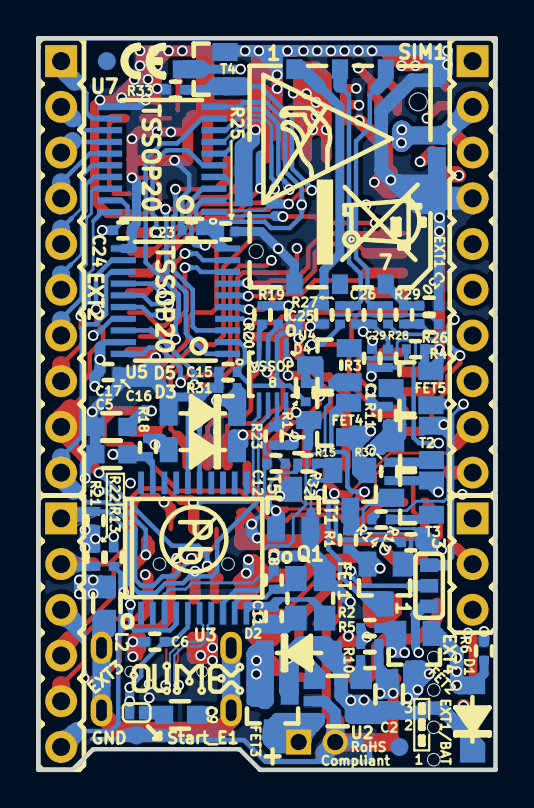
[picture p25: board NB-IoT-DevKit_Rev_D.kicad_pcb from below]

Board: 4 copper layers, 25.4 x 40.6 mm, 116 parts (82 on the bottom side), 93 nets.

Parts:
3.3V/VCCB1: Soldered/Opened; SJ_2_SMALL
3.3V_E1: Soldered; SJ_1_SMALLER
ANT1: U.FL-R-SMT-1
BAT1: DW02S; LIPO_BAT_VERTICAL_DW02S
BAT/EXT1: BAT:Soldered/EXT:Opened; SJ_2_SMALL
C1: 1nF/50V/10%/X7R/C0402; C_0402_5MIL_DWS
C2, C3, C4, C5, C9, C27, C28: 22uF/6.3V/20%/X5R/C0603; C_0603_5MIL_DWS
C6, C12, C15, C16, C20, C23, C24, C25: 100nF/10V/10%/X5R/C0402; C_0402_5MIL_DWS
C8, C11: 27pF/50V/5%/C0G/C0402; C_0402_5MIL_DWS
C13, C14, C22: NA/C0402; C_0402_5MIL_DWS
C17: 4.7uF/6.3V/20%/X5R/C0603; C_0603_5MIL_DWS
C18, C19: 47uF/6.3V/20%/X5R/C0805; C_0805_5MIL_DWS
C21, C26, C29, C30: 33pF/50V/5%/COG/C0402; C_0402_5MIL_DWS
CHRG1: LED/YELLOW/0603; LED_0603_KA
D1, D2, D3, D5: 1N5819S4/SOD123; SOD-123_1C-2A_KA
D4: BAT54A(SOT23-3); SOT23-3
EXT1, EXT2: HN1x10
EXT3: HN1x6
EXT4: HN1x3
FET1, FET2, FET3: WPM2015-3/TR; SOT23
FET4, FET5: BSS138(SOT23-3); SOT23
FID1, FID2, FID3, FID4: Fiducial; Fiducial1x3
GND_Pin1: TESTPAD; TESTPAD_40-ROUND
L1: 2.2uH/1.5A/DCR=72mR/20%/3.00x3.00x1.50mm/CD32(NR3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; CD32
L2: FB0603/600R/200mA(160808-601); L_0603_5MIL_DWS
L3: 0R/R0402; L_0402_5MIL_DWS
LED_Netlight1: LED/Green/0603; LED_0603_KA
Logo_OLimeX: LOGO_OLIMEX_80
Olimex_Logo1: LOGO_OLIMEX_80
PWR_KEY1: IT1185AU2; IT1185AU2_V2
Q1: Q12MHz/20pF/10ppm/4P/3.2x2.5mm; TSX-3.2x2.5mm_GND(3)
R1, R31: 100k/R0402; R_0402_5MIL_DWS
R2, R3, R13, R25, R32, R33: 1M/R0402; R_0402_5MIL_DWS
R4, R5: 470k/R0402; R_0402_5MIL_DWS
R6, R16, R26: 10k/R0402; R_0402_5MIL_DWS
R7, R10: 2.2k/R0402; R_0402_5MIL_DWS
R8, R23: 220k/R0402; R_0402_5MIL_DWS
R9: 49.9k/1%/R0402; R_0402_5MIL_DWS
R11, R12: 100R/R0402; R_0402_5MIL_DWS
R14, R17, R19, R20, R30: 1.5k/R0402; R_0402_5MIL_DWS
R15, R18, R21, R22: 4.7k/R0402; R_0402_5MIL_DWS
R24: NA/R0402; R_0402_5MIL_DWS
R27, R28, R29: 22R/R0402; R_0402_5MIL_DWS
RST_KEY1: IT1185AU2; IT1185AU2_V2
SIM1: SIMNANO-6P-1.3H
Sign_Antistatic: Val**; LOGO_ANTISTATIC_1
Sign_CE_Small: CE_Sign_Small
Sign_PbFree: LOGO_PBFREE
Sign_RecycleBin: LOGO_RECYCLEBIN_1
Start_E1: Soldered; SJ_1_SMALLER
T1, T4, T5: BSS138(SOT23-3); SOT23
T2, T3: BC817(SOT23-3); SOT23
U1: SY8089AAAC(SOT23-5); SOT-23-5
U2: BL4054B-42TPRN(SOT23-5); SOT-23-5
U3: CH340T(SSOP20W); SSOP-20W
U4: PCA9306DCUR(VSSOP-8); VSSOP-8_Pitch-0.50mm_Pad-0.25mm_Dimensions-2.30x2.00x1.00mm
U5, U7: TXB0108PWR(TSSOP-20); TSSOP20_Pitch-0.65mm_6.6x4.5x1.2mm
U6: Quectel_NB-IoT_BC66_Module(Pinout-OpenCPU); Quectel_NB-IoT_BC66_Module-17.7mmx15.8mmx2.0mm
USB-UART1: MISB-SWMM-5B-LF(USB_MICRO); USB-MICRO_MISB-SWMM-5B_LF
VR1: AP1231-1.8V(SOT23-5); SOT-23-5
mUEXT1: HAB-VCR-010-LF

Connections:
+1.8V: C15.2, C23.2, C28.1, FET4.1, R17.2, R19.2, R20.2, R24.2, R25.2, T1.1, U4.2, U5.2, U5.10, U7.2, U7.10, VR1.5
+3V3: 3.3V/VCCB1.3, 3.3V_E1.1, C5.1, C6.1, C18.1, C19.1, C20.1, C21.1, C22.1, C27.1, R13.2, R18.1, Start_E1.2, U3.5, U3.19, U6.42, U6.43, VR1.1, mUEXT1.1
+5V: C2.1, CHRG1.2, D1.1, D2.2, EXT4.1, FET2.2, FET3.1, LED_Netlight1.2, R2.1, U2.4
+5V_EXT: D1.2, EXT1.1, FET2.1, R6.2
+5V_USB: FET2.3, USB-UART1.1
/ADC0: C1.1, R3.2, R4.1, U6.9
/ADC0toEXT: BAT/EXT1.3, EXT1.7
/CH340(TxD): D4.1, U3.3
/CTS-AUX: EXT2.8, U7.20
/CTS_AUX\PWR-SENS: R2.2, R5.1, U6.22, U7.1
/DTR: R30.1, T3.2, U3.15
/GPIO1: EXT2.1, U7.12
/GPIO1(EINT): U6.26, U7.9
/GPIO2: EXT2.2, U7.13
/GPIO2(EINT): U6.30, U7.8
/GPIO3: EXT2.3, U7.14
/GPIO3(PWM3): U6.31, U7.7
/GPIO4: EXT2.4, U7.15
/GPIO4(EINT): U6.32, U7.6
/GPIO5: EXT2.5, U7.16
/GPIO5(EINT): U6.33, U7.5
/I2C0-SCL(RI): EXT3.1, R21.1, U4.6, mUEXT1.5
/I2C0-SDA(DCD): EXT3.2, R22.1, U4.5, mUEXT1.6
/I2C0_SCL(EINT): R19.1, U4.3, U6.20
/I2C0_SDA(EINT): R20.1, U4.4, U6.21
/Netlight: EXT2.6, U7.17
/Netlight(PWM0): R33.1, T4.1, U6.16, U7.4
/PSM_EINT: T5.3, U6.19
/PSM_EINTn: EXT1.10, R32.1, T5.1
/PWR_KEY: EXT1.8, R11.1, U6.7
/RST_KEY: EXT1.9, R12.1, U6.15
/RTS: R14.1, T2.2, U3.16
/RTS-AUX: EXT2.7, U7.18
/RTS_AUX(PWM2): U6.23, U7.3
/RxD: D3.1, EXT4.2, FET4.3, R15.1
/RxD-AUX: EXT2.10, U5.13, mUEXT1.4
/RxD-DBG: EXT1.5, U5.18
/RxD_AUX(EINT): U5.8, U6.28
/RxD_DBG(EINT): U5.3, U6.38
/RxD_MAIN: D4.3, R17.1, U6.18
/SIM_CLK: R28.2, U6.13
/SIM_DATA: R26.2, R29.2, U6.11
/SIM_RST: R27.2, U6.12
/SIM_VDD: C25.1, R26.1, SIM1.1, U6.14
/SPI-CS: EXT3.6, R13.1, U5.17, mUEXT1.10
/SPI-MISO: EXT3.3, U5.14, mUEXT1.7
/SPI-MOSI: EXT3.4, U5.15, mUEXT1.8
/SPI-SCLK: EXT3.5, U5.16, mUEXT1.9
/SPI_CS(EINT): U5.4, U6.6
/SPI_MISO(EINT): U5.7, U6.3
/SPI_MOSI(EINT): U5.6, U6.4
/SPI_SCLK(EINT): U5.5, U6.5
/TxD: D4.2, EXT4.3
/TxD-AUX: EXT2.9, U5.12, mUEXT1.3
/TxD-DBG: EXT1.6, U5.20
/TxD_AUX(EINT): U5.9, U6.29
/TxD_DBG(EINT): U5.1, U6.39
/TxD_MAIN: FET4.2, U6.17
/USB_D+: U3.6, USB-UART1.3
/USB_D-: U3.7, USB-UART1.2
/VCCB: C16.2, C24.2, FET1.3, R15.2, R21.2, R22.2, R23.2, U5.19, U7.19
/VCCB(3.3V): 3.3V/VCCB1.1, EXT1.3
GND: ANT1.2, BAT1.2, C1.2, C2.2, C3.2, C4.2, C5.2, C6.2, C8.2, C11.2, C12.2, C13.1, C14.1, C15.1, C16.1, C17.1, C18.2, C19.2, C20.2, C21.2, C22.2, C23.1, C24.1, C25.2, C26.1, C27.2, C28.2, C29.1, C30.1, D5.2, EXT1.4, FET5.2, GND_Pin1.1, L2.2, PWR_KEY1.2, Q1.3, R4.2, R5.2, R6.1, R9.2, R10.2, R25.1, R31.1, R32.2, R33.2, RST_KEY1.2, SIM1.0, SIM1.5, T1.2, T4.2, T5.2, U1.2, U2.2, U3.8, U4.1, U5.11, U6.1, U6.10, U6.27, U6.34, U6.36, U6.37, U6.40, U6.41, U7.11, USB-UART1.5, VR1.2, mUEXT1.2
unnamed: 3.3V/VCCB1.2, FET1.2, R1.1
unnamed: 3.3V_E1.2, C4.1, L1.2, R8.2
unnamed: ANT1.1, C13.2, L3.2
unnamed: BAT/EXT1.2, R3.1
unnamed: C3.1, D2.1, FET3.2, U1.1, U1.4
unnamed: C8.1, Q1.1, U3.9
unnamed: C9.1, Start_E1.1
unnamed: C9.2, D5.1, FET5.1, R31.2
unnamed: C11.1, Q1.2, U3.10
unnamed: C12.1, R23.1, U4.7, U4.8
unnamed: C14.2, L3.1, U6.35
unnamed: C26.2, R27.1, SIM1.2
unnamed: C29.2, R28.1, SIM1.3
unnamed: C30.2, R29.1, SIM1.7
unnamed: CHRG1.1, R7.1
unnamed: D3.2, R18.2, U3.4
unnamed: FET1.1, R1.2, T1.3
unnamed: FET5.3, PWR_KEY1.1, R11.2, T2.3
unnamed: L1.1, U1.3
unnamed: L2.1, USB-UART1.0
unnamed: LED_Netlight1.1, R16.1
unnamed: R7.2, U2.1
unnamed: R8.1, R9.1, U1.5
unnamed: R10.1, U2.5
unnamed: R12.2, RST_KEY1.1, T3.3
unnamed: R14.2, T3.1
unnamed: R16.2, T4.3
unnamed: R30.2, T2.1
VBAT: BAT1.1, BAT/EXT1.1, EXT1.2, FET3.3, U2.3
VDD_1.8V: C17.2, R24.1, U6.24, VR1.3

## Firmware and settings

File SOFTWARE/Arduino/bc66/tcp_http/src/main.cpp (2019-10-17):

#include <Arduino.h>
#include <nbClient.h>

nbClient tcp;
#define HOST "wizio.eu"

void tcp_http()
{
  int timeout = 0;
  int r = tcp.connect(HOST, 80);
  DBG("connect: %d\n", r);
  if (r == 1)
  {
    char data[] = "GET /iot.php HTTP/1.1\r\nHost:" HOST "\r\n\r\n";
    r = tcp.write(data, strlen(data));
    DBG("sent: %d\n", r);
    delay(100);
    do
    {
      while (tcp.available())
      {
        r = tcp.read(); // read byte
        if (r > 0)
          Serial.print((char)r); // print result
        else
          goto end;
      }
      delay(100);
    } while (++timeout < 100);
  end:
    delay(10);
  }
  tcp.stop();
}

void setup() {
  String imei;
	Dev.setBand(3);
  Dev.noSleep();
  Serial.begin(115200);
  Serial.printf("Arduino %s\n", Dev.getVersion());
  Dev.getImei(imei);
  Serial.printf("IMEI %s\n", imei.c_str());
  Dev.waitSimReady();
  Serial.println("Sim Ready");
  Dev.waitCereg();
  delay(200); // must
  Serial.println("Net Ready");
  Serial.println("Test TCP\n");
  tcp_http();
  pinMode(LED, OUTPUT);
}

void loop() {
  static int led = 0;
  delay(500);
  digitalWrite(LED, ++led & 1);
}

/*
Arduino BC66NBR01A04
IMEI 867997030026081
Sim Ready
Net Ready
Test TCP
HTTP/1.1 200 OK
Date: Wed, 03 Apr 2019 06:44:09 GMT
Server: Apache
Upgrade: h2,h2c
Connection: Upgrade
Cache-Control: max-age=0
Expires: Wed, 03 Apr 2019 06:44:09 GMT
Content-Length: 47
Content-Type: text/html
[WIZIO.EU] Hello World ( 2019-04-03 09:44:10 )
*/

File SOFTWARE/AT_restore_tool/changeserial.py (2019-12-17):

#!/usr/bin/env python2

# BC66 repair tool
# Copyright (C) 2019  OLIMEX

#This program is free software: you can redistribute it and/or modify
#it under the terms of the GNU General Public License as published by
#the Free Software Foundation, either version 3 of the License, or
#(at your option) any later version.

#This program is distributed in the hope that it will be useful,
#but WITHOUT ANY WARRANTY; without even the implied warranty of
#MERCHANTABILITY or FITNESS FOR A PARTICULAR PURPOSE.  See the
#GNU General Public License for more details.

#You should have received a copy of the GNU General Public License
#along with this program.  If not, see <http://www.gnu.org/licenses/>.


import serial
import sys

max_tries = 5

def sendAT(cmd):
	command = cmd + "\n\r"
	tried=0
	BREAK = 0
	while (tried < max_tries) and BREAK == 0:
		com.write(bytes(command))
		for i in range(3):
			data = com.readline()
			if "OK" in data:			
				BREAK=1
				break
		tried+=1
	if  BREAK == 1:
		return True
	else:
		return False
	

def checkSN():
	data = ""
	for i in range(3):
		com.write(bytes("AT+CGSN=0\n"))
		for i in range(3):
			data = com.readline()
			if data not in ["OK", "ERROR", "", "ok", "error", " "] :
				break
	if SN not in data:
		return True
	else:
		return False
def checkIMEI():
	data = ""
	for i in range(3):
		com.write(bytes("AT+CGSN=1\n"))
		for i in range(3):
			data = str(com.readline())
			if data not in ["OK", "ERROR", "", "ok", "error", " "] :
				break
	if IMEI not in data:
		return True
	else:
		return False

if (len(sys.argv)) < 4 or "--help" in sys.argv:
	print("\033[36mUsage: python changeserial.py <SN> <IMEI> <SerialPort>\033[0m")
	print("")
	sys.exit(1)

PORT = sys.argv[1]
SN = sys.argv[2]
IMEI = str(sys.argv[3])


if "MPA" not in SN or len(SN) != 15:
	print("\033[31m Wrong SN number\033[0m")
	sys.exit(1)

if len(IMEI) != 15:
	print("\033[31m Wrong IMEI number\033[0m")
	sys.exit(1)



sys.stdout.write("\n")
sys.stdout.write("Openning \""+ PORT + "\"" + "............")
sys.stdout.flush()

try:
	com = serial.Serial(PORT, baudrate=115200, timeout=0.4)
except:
	sys.stdout.write("\033[31m[ FAILED ] \033[0m\n")
	sys.stdout.write("\033[31mThe board is not connected OR wrong Serial Port\033[0m")
	sys.stdout.flush()
	exit(1)

''' Check if board responds to "AT" '''

if not sendAT("AT"):
	sys.stdout.write("\033[31m[ FAILED ] \033[0m\n")
	print("\033[31m Board doesn't answer\033[0m")	
	sys.exit(1)
else:
	sys.stdout.write("\033[32m[ SUCCESS ] \033[0m\n")


AT_LIST = ["AT+CFUN=0", "AT*MNVMQ=\"1.0\"", str("AT*MCGSN=0,\"" + SN + "\""), str("AT*MCGSN=1,\"" + IMEI + "\"")]


''' Change SN and IMEI numbers '''
for cmd in AT_LIST:
	if sendAT(cmd) == False:
		print("\033[31mCouldn't send {}\033[0m".format(cmd))
		sys.exit(1)
	

''' Reset the board '''
if not sendAT("AT+QRST=1"):
	print("\033[31mCouldn't send {}\033[0m".format("AT+QRST=1"))
	sys.exit(1)

''' Baudrate sync '''
if not sendAT("AT"):
	print("\033[31mCouldn't send {}\033[0m".format("AT"))
	sys.exit(1)

''' Check if SN and IMEI are changed '''

if (checkSN() and checkIMEI()):
	print("\033[32m============== BOARD RESTORED SUCCESSFULLY!!! ============== \033[0m")
else:
	print("\033[31m============== BOARD RESTORED UNSUCCESSFULLY!!! ============== \033[0m")

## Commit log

2019-10-17 initial upload of hardware and software files
    [BAT54.step, GBH2x5.stp, HN1x10-PinHeader_1x10_P2.54mm_Vertical.step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]
2024-01-04 Update
    Added hardware revisions C and D and hardware revision changes.
    [BAT54.step, Extension_Rev_B.kicad_pcb, Extension_Rev_B.sch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]

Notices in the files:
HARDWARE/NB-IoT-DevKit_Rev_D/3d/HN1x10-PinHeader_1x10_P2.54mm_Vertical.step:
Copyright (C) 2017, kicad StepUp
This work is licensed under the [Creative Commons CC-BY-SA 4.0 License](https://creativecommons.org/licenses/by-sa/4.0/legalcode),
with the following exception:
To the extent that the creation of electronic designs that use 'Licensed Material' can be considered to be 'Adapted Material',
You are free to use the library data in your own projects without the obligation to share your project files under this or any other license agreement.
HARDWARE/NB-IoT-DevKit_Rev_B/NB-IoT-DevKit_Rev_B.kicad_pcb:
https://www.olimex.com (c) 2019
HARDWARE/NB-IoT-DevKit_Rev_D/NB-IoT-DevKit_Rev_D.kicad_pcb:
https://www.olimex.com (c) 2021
